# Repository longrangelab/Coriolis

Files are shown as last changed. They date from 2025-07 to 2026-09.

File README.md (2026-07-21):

# Coriolis
Coriolis is an open-source,long-range, digital platform that is capable of hosting a variety of sensors built for long-range precision shooters. 

Discord link for build questions or to chat about ideas: https://discord.gg/T3Q2JN2y2S

This video briefly describes Coriolis and what it can do: https://www.youtube.com/watch?v=9miKXuf_NCE&t=154s

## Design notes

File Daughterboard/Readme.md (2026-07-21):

# Coriolis Daughterboard

This directory contains the source files and manufacturing data for the Coriolis daughterboard. Unless you are experienced with electronics, I would recommend you select "PCB + Assembly." 

## Order a PCB

You can order this PCB directly from PCBWay using the link below.

<a href="https://www.pcbway.com/project/shareproject/Coriolis_Long_Range_Wind_Measurement_e642d0fc.html">
  Order Coriolis Daughterboard from PCBWay
</a>

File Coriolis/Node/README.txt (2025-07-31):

#####	HOW TO USE   #####
*For Target-Device
1.Uncomment line 11  #define IS_TARGET if this line is being commented
2.Upload to device ,check serial log

*For User-Device
1.Comment line 11  #define IS_TARGET if this line is being uncommented
2.Upload to device ,check serial log

If there is anything unusual, please let me know and I will correct it for you immediately.

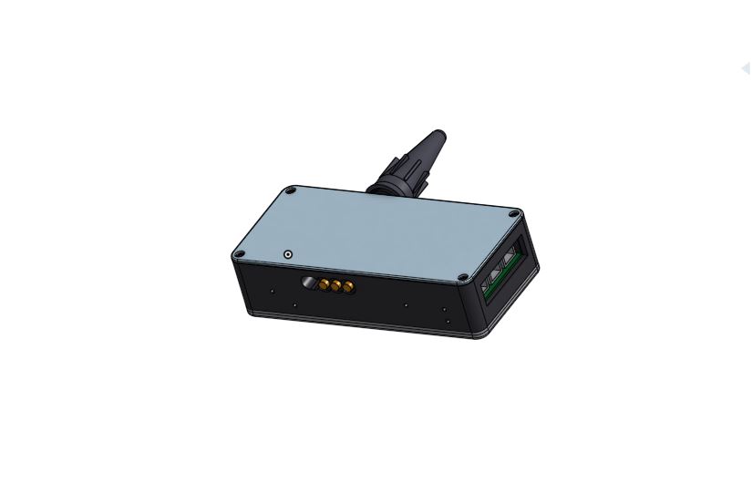
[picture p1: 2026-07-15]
Schematics and Photos/Color Case.JPG

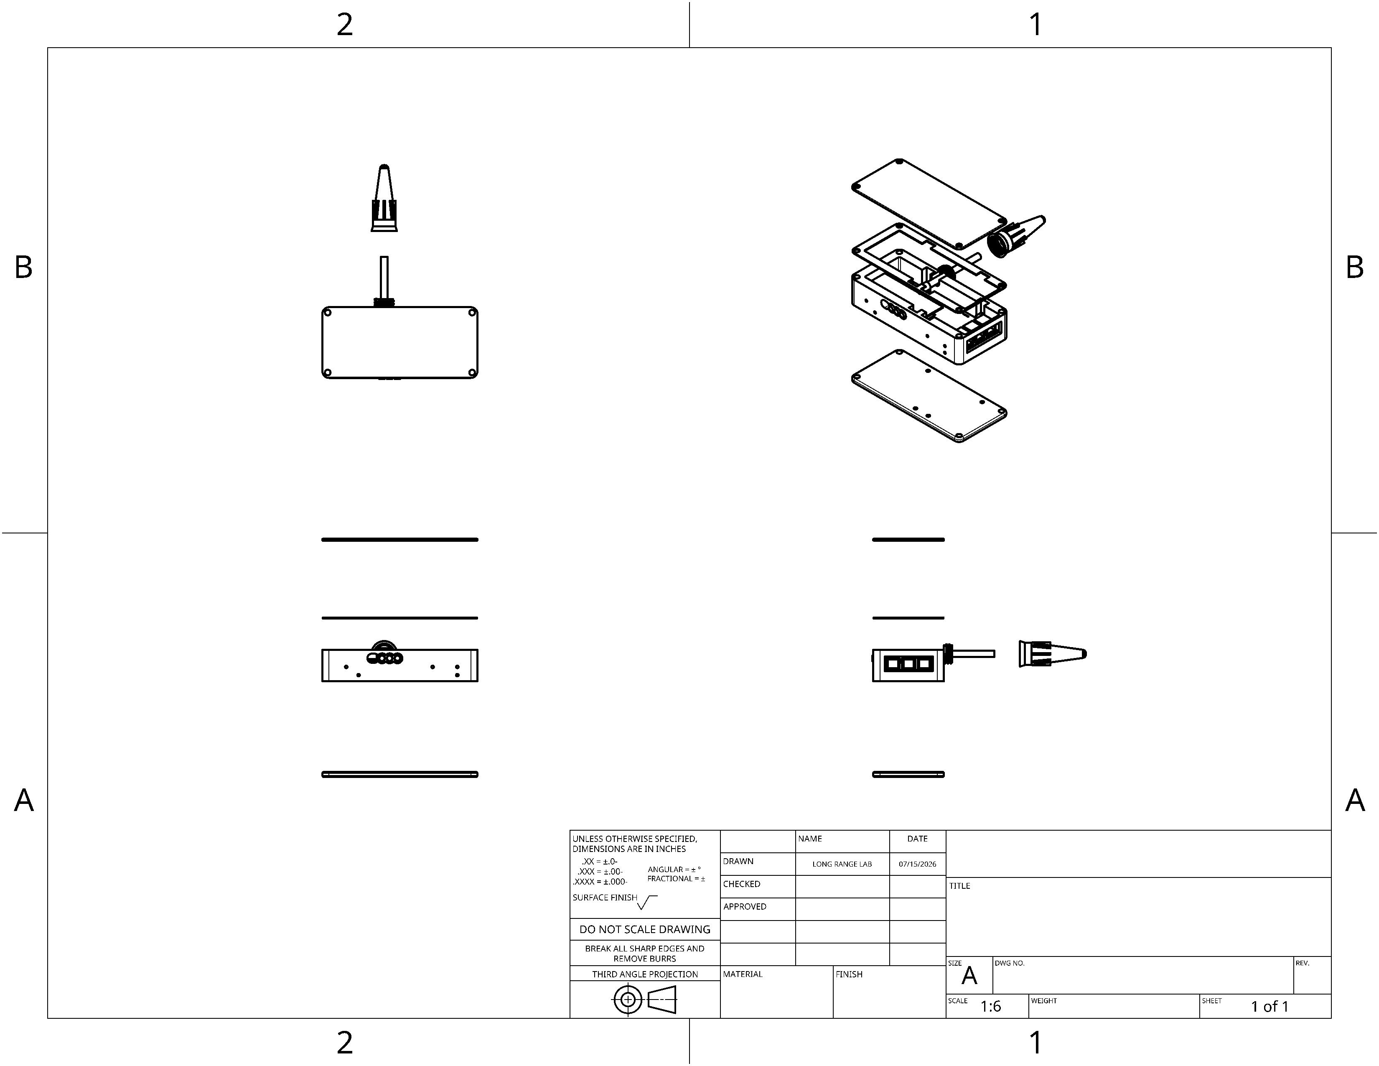
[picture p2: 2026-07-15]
Schematics and Photos/Github CaseDrawing.jpeg

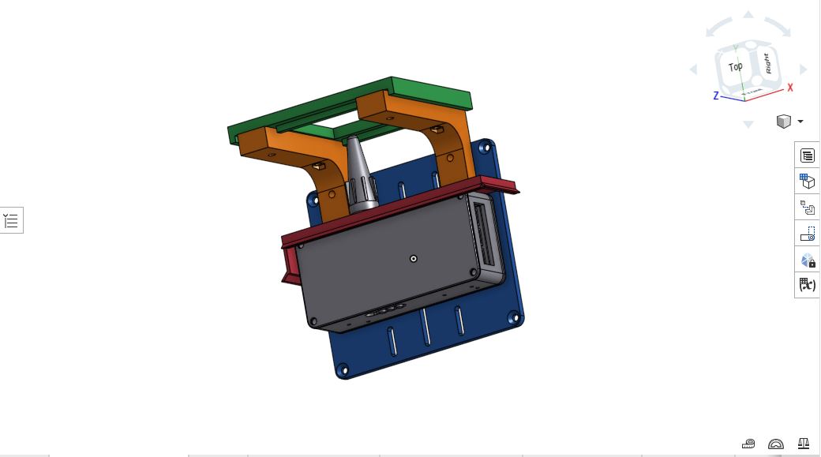
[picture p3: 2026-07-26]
Solar Panel Fixture/Solar node finished.JPG

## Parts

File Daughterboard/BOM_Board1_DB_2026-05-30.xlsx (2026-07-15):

No. | Quantity | Comment | Designator | Footprint | Value | Manufacturer Part | Manufacturer | Supplier Part | Supplier | Pins | Antenna Type | JLCPCB Stock | JLCPCB Price | Description | Diode Configuration
1 | 1 | 100nF | C1 | CAP-TH_L5.8-W2.4-P2.54-D0.6 | 100nF | CC1H104ZA1ED3F5P1100 | Dersonic(德尔创) | C2832506 | LCSC | 2 |  | 98323 | 0.0033 | Capacitance:100nF Tolerance:-20%~+80% Tolerance:-20%~+80% Voltage Rating:50V Pin Spacing:2.54mm Temperature Coefficient:Y5V Diameter:5.8mm Body Thickness:2.4mm
2 | 3 | R-RJ45R10P-B000 | J1,J2,J3 | RJ45-TH_R-RJ45R10P-B000 |  | R-RJ45R10P-B000 | Ckmtw(灿科盟) | C386758 | LCSC | 10 |  | 44898 | 0.0574 | Connector Type:RJ45 Jack Mounting Type:Right Angle Number of Ports:1 LED:Non-LED Shielding:Shielded Ratings:- Supplementary Features:Harpoon Contact (Plastic) Contact Material:Phosphor Bronze Contact Plating:Gold Operating Temperature:0℃~+70℃ Operating Te
3 | 3 | PM254V-11-04-H85 | J4_OLED,J4_SENSOR,J4_SENSOR1 | HDR-TH_4P-P2.54-V-F |  | PM254V-11-04-H85 | XFCN(兴飞) | C541851 | LCSC | 4 |  | 60552 | 0.0103 | Holes Structure:1x4P Pitch:2.54mm Row Spacing:- Circular Hole / Square Hole:Square Hole Mounting Type:Through Hole Number of Rows:1 Number of Positions:4P Current Rating:3A Holes Direction:Top Insulation Height:8.5mm Contact Material:Brass Contact Plating
4 | 1 | DY-333YD-SN-A3(EL) | LED1 | LED-TH_BD5.0-P2.54-FD-1 |  | DY-333YD-SN-A3(EL) | TONYU(东裕) | C7470706 | LCSC | 2 |  | 852 | 0.0056 | Lamp Holder Type:5mm round lamp head Illumination Color:Yellow Voltage - Forward(Vf):2.4V Voltage - Forward(Vf):2.4V Power(Watts):60mW Forward Current:20mA Wavelength - Dominant:592nm Wavelength - Dominant:592nm Peak Wavelength:584nm Diode Configuration:D | Discrete Diode
5 | 1 | 100Ω | R1 | RES-TH_BD2.4-L6.3-P10.30-D0.6 | 100Ω | MFR50SJT-52-100R | YAGEO(国巨) | C176622 | LCSC | 2 |  | 4514 | 0.0023 | Type:Metal Film Resistors Resistance: Tolerance:±5% Tolerance:±5% Power(Watts):500mW Operating Temperature:-55℃~+155℃ Operating Temperature:-55℃~+155℃
6 | 2 | 10kΩ | R2,R3 | RES-TH_BD2.4-L6.3-P10.30-D0.6 | 10kΩ | MFR50SJT-52-10K | YAGEO(国巨) | C176623 | LCSC | 2 |  | 2140 | 0.0025 | Type:Metal Film Resistor Resistance:10kΩ Tolerance:±5% Tolerance:±5% Voltage-Supply(Max):- Power(Watts):500mW Operating Temperature:-55℃~+155℃ Operating Temperature:-55℃~+155℃
7 | 2 | 4.7kΩ | R4,R5 | RES-TH_BD2.2-L6.5-P10.50-D0.6 | 4.7kΩ | MFR50SJT-52-4K7 | YAGEO(国巨) | C176641 | LCSC | 2 |  | 9861 | 0.0024 | Type:Metal Film Resistors Resistance: Tolerance:±5% Tolerance:±5% Power(Watts):500mW Operating Temperature:-55℃~+155℃ Operating Temperature:-55℃~+155℃
8 | 2 | FH-00780 | U4,U5 | HDR-TH_13P-P2.54-V-F |  | FH-00780 | Liansheng(连盛) | C2685211 | LCSC | 13 |  | 3597 | 0.0174 | Holes Structure:1x13P Pitch:2.54mm Row Spacing:- Circular Hole / Square Hole:Square Holes Mounting Type:Straight Number of Rows:Plugin Number of Holes:13P Current Rating (Max):3A Voltage Rating (Max):- Holes Direction:Top Insulation Height:8.5mm Operating
9 | 1 | DS1009-08AT1NX-0A2 | U6 | DIP-8_L10.2-W10.2-P2.54-LS7.6-BL |  | DS1009-08AT1NX-0A2 | CONNFLY | C72124 | LCSC | 8 |  | 68990 | 0.0043 | Adaptation Package Type:DIP Pitch:2.54mm Row Spacing:7.62mm Circular Holes/Square Holes:Square Hole Number of Positions:8P Contact Plating:Tin Operating Temperature:-20℃~+105℃ Operating Temperature:-20℃~+105℃

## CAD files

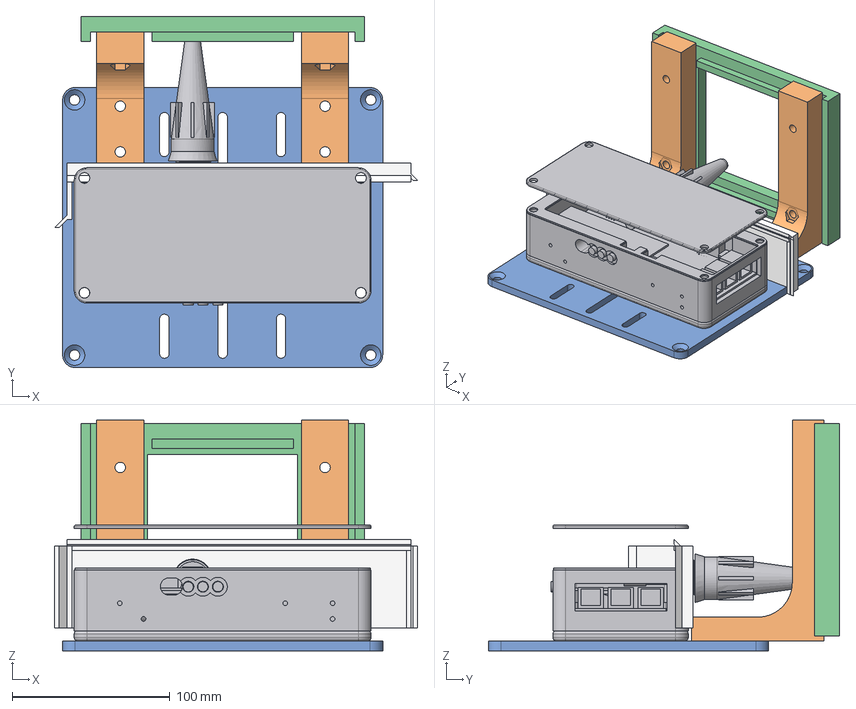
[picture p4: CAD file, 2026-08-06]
Solar Panel Fixture/Solar Node Complete.step
230.4 x 222.9 x 146.3 mm
riser_L
platform
backer_plate
riser_R
node x 21

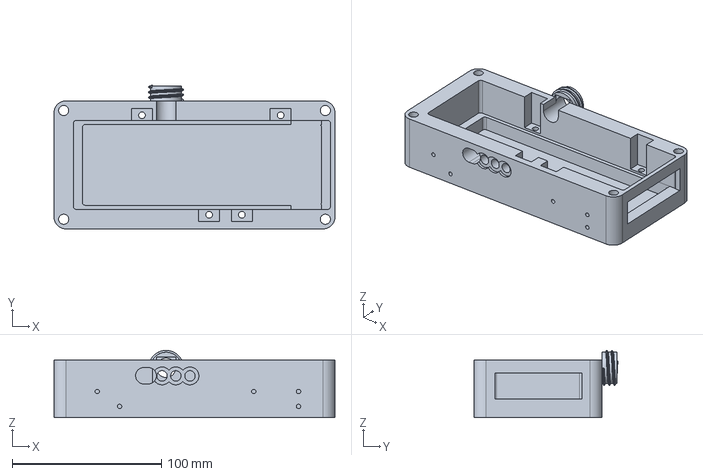
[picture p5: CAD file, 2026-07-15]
STL's/Individual Case Parts/Main Enclosure.step
188.5 x 96.5 x 45.1 mm

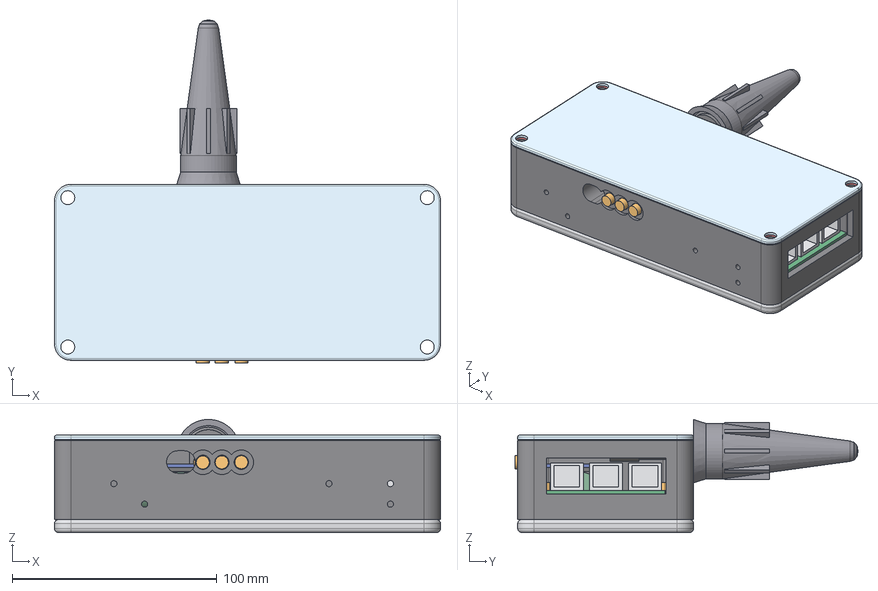
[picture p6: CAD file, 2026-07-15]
STL's/Daughterboard Case V1.step
188.5 x 167.6 x 55.2 mm
TBeam_antenna_whip
carrier_pcb
base_aluminum
strap_1
push_button_x3_v7 x 3
strap_4
lid_clear
TBeam_antenna_base
middle_printed
antenna_cover
RJ45_J1
strap_3
gasket_tpu_v8
TBeam_18650_holder
RJ45_J2
strap_2
RJ45_J3
TBeam_PCB
TBeam_18650_cell

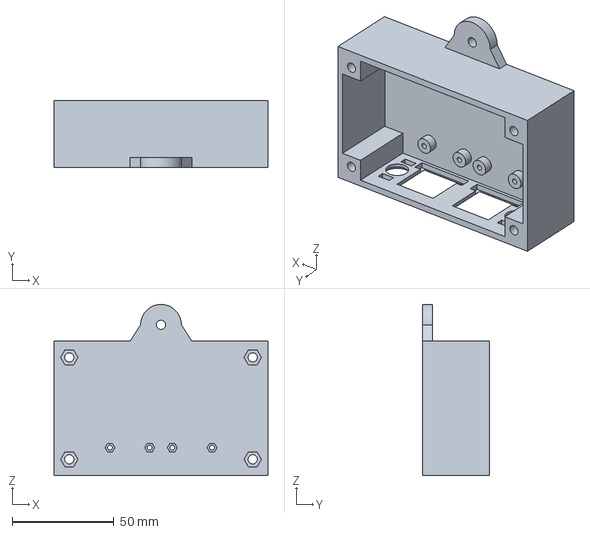
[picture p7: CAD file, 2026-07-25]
STL's/Wind Meter Mounting Options/rj45_body.step
105.0 x 33.0 x 84.0 mm

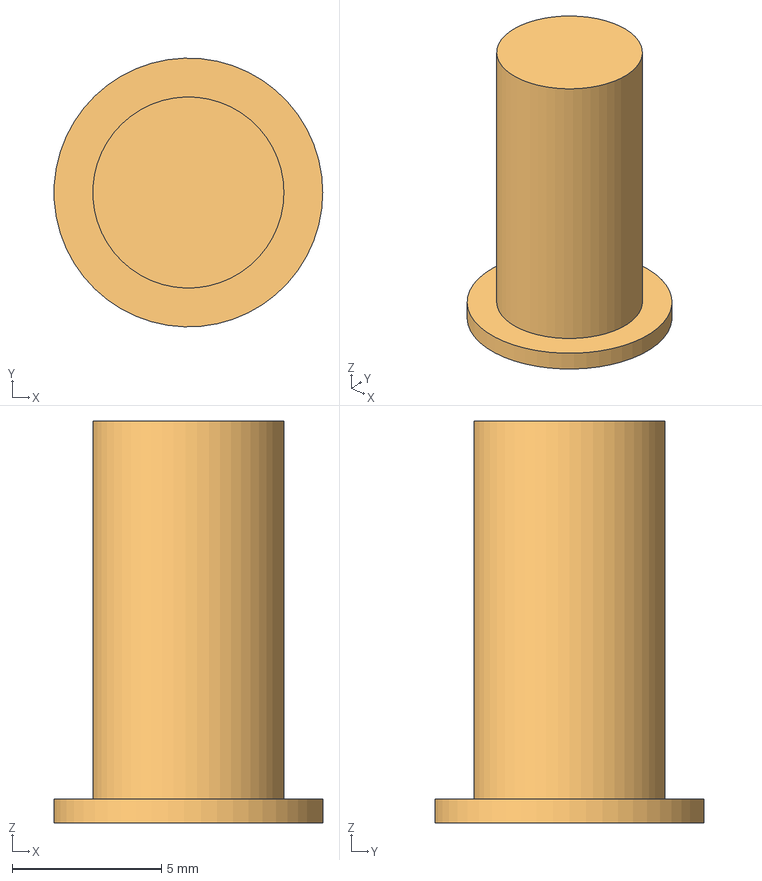
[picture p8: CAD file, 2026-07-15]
STL's/Individual Case Parts/Push Button.step
8.99 x 9.00 x 13.5 mm

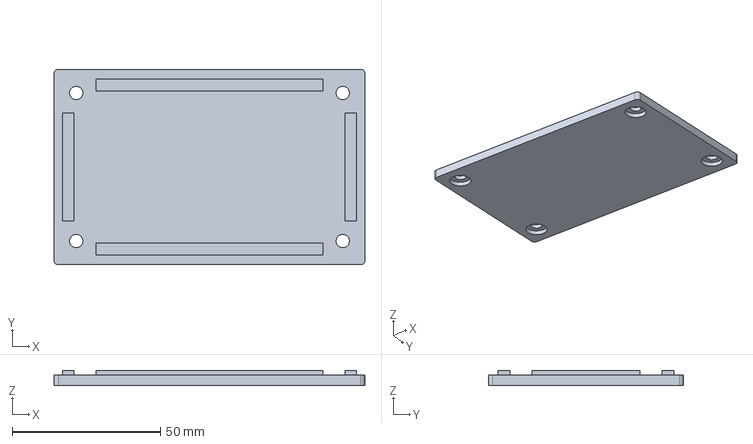
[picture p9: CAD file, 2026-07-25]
STL's/Wind Meter Mounting Options/rj45_lid.step
105.0 x 66.0 x 5.10 mm

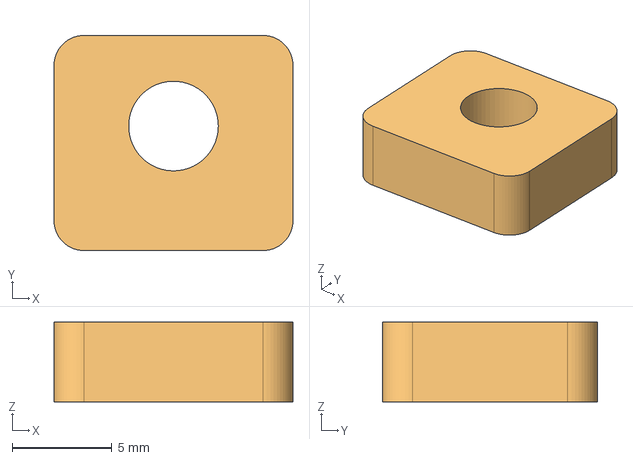
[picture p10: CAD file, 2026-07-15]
STL's/Individual Case Parts/PCB Strap.step
12.0 x 10.8 x 4.00 mm

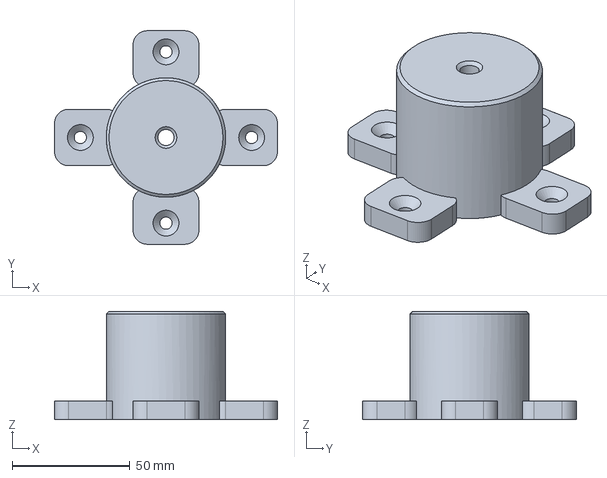
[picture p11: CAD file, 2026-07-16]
STL's/Wind Meter Mounting Options/Ballhead Post Mount.step
94.8 x 90.8 x 46.1 mm

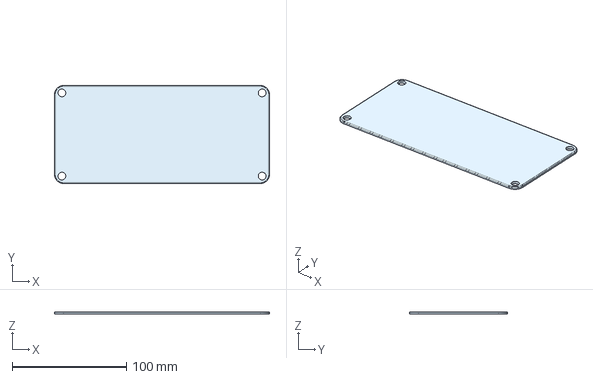
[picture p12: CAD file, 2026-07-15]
STL's/Individual Case Parts/2mm Acrylic Lid.step
188.5 x 85.9 x 2.16 mm

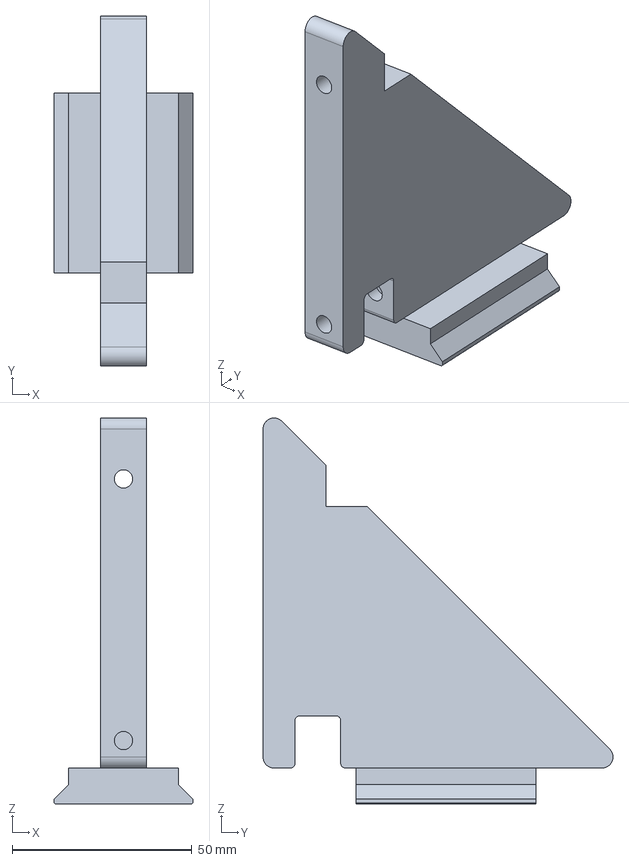
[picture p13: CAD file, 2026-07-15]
STL's/Wind Meter Mounting Options/Inspeed Arca Mount.step
38.6 x 97.3 x 107.3 mm

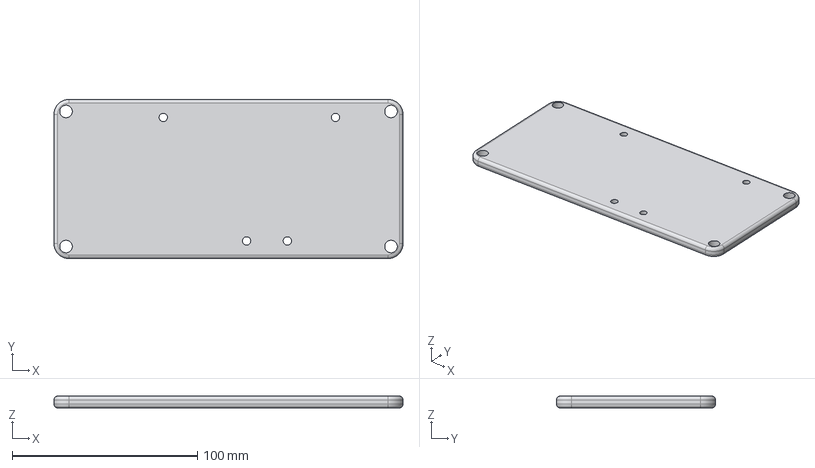
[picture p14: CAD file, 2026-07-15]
STL's/Individual Case Parts/Optional - Aluminum Bottom.step
188.5 x 85.9 x 6.35 mm

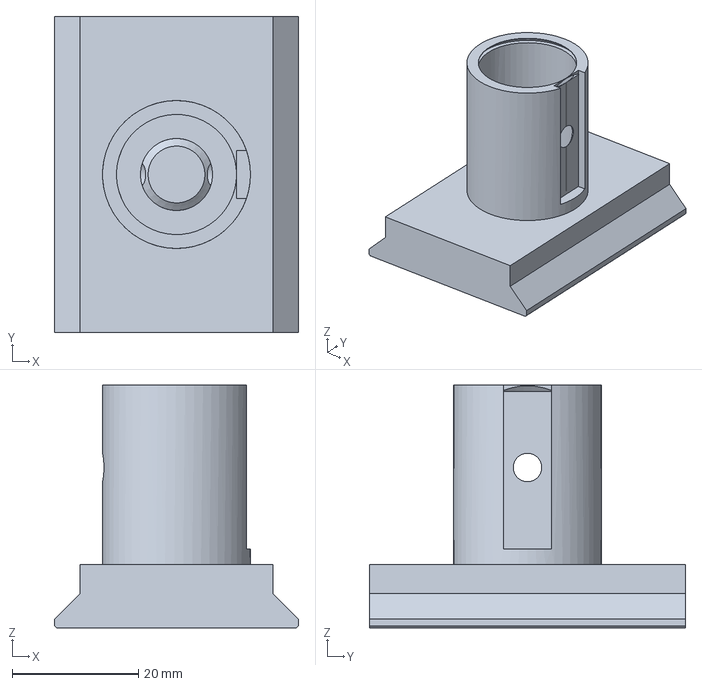
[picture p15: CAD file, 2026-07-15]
STL's/Wind Meter Mounting Options/Sparkfun Wind Arm Arca Mount.step
38.6 x 50.0 x 38.4 mm

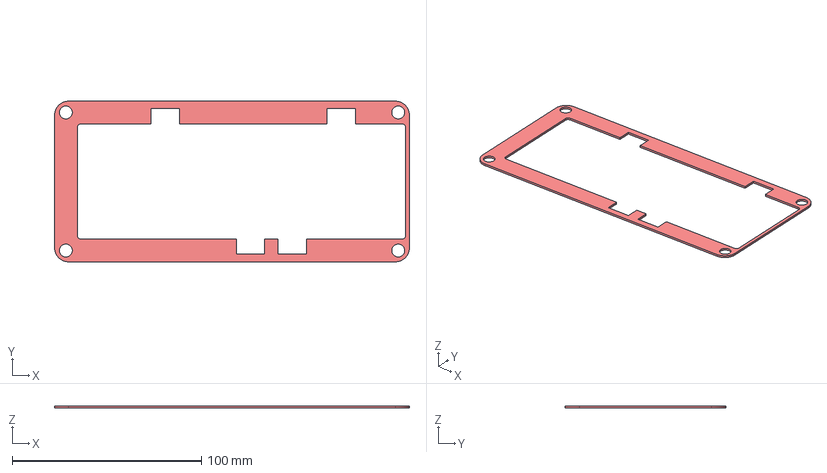
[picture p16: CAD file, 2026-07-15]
STL's/Individual Case Parts/TPU Lid Gasket.step
187.5 x 84.9 x 1.20 mm

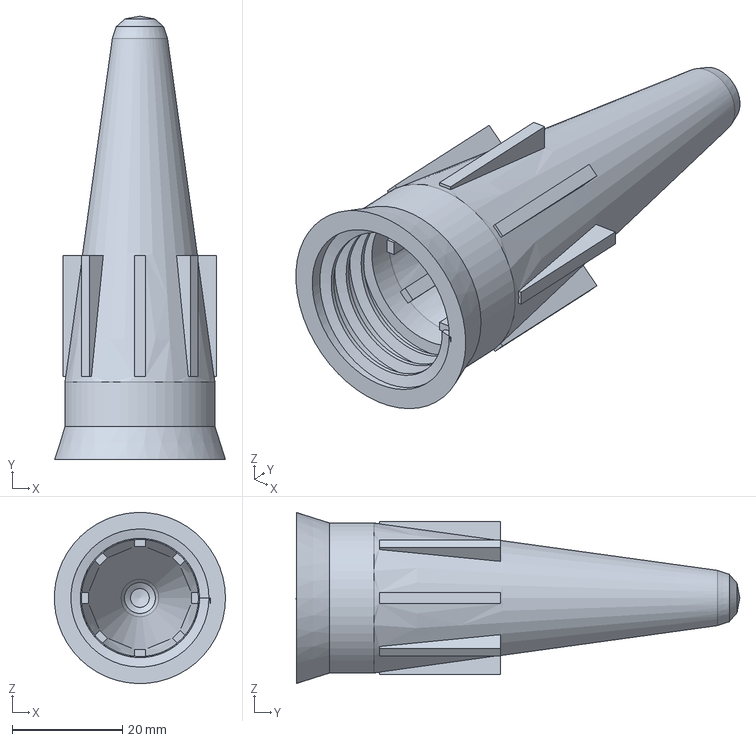
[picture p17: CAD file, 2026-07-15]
STL's/Individual Case Parts/Screw-On Cover for Factory Antenna.step
31.0 x 80.3 x 31.0 mm

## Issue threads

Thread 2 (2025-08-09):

3D models?

edgan, 2025-08-09:
There are currently no 3D models(STLs?) in the git repository.

edgan, 2025-08-13:
I see that. The directory structure should be improved.

`Weather Meter V1.0` -> `3d-models/weather-meter`

Using anything like `v1.0` in a directory name in git is silliness. That is what tags and releases are for.

Also the filenames are so long I can't even see they are `STL` files.

I will make a pull request for the naming.

There is no STLs for the dial part. I will make a new issue for that.

Closed 2025-08-13.

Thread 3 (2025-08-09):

Detailed parts list?

edgan, 2025-08-09:
Pulled from the YouTube video:
Mounting – 3D-printed PLA bracket ([Arken Optics LH4 6-24](https://opticsforce.com/products/arken-optics-lh4-6-24x50-ffp-capped-tool-less-turrets-illuminated-vhr-vpr-30mm-tube), discontinued).

Motion – Stepper motor + 5:1 gearbox for torque, driven by a [DRV8825](https://www.pololu.com/product/2133) driver.

Power – RC car battery.

Control – [Arduino](https://www.arduino.cc/) microcontroller running simple but precise early-stage firmware.

Ideas:
1. 3D models https://github.com/longrangelab/Coriolis/issues/2
2. Motors
3. Batteries, voltage? 2S, 4S, or 6S?
4. Scope, given the current one is discontinued, support different obtainable scopes
5. Exact Arduino boards
6. Multiple links for products and places to purchase. Manufacture, Amazon, etc

longrangelab, 2025-08-16:
Still working on this at the moment. I have listed the main parts for the Weather Station, the Base Unit, and the Target unit. Still selecting final components for FAWD and the User Interface.

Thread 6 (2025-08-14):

Help with PCBs

MitkoDyakov, 2025-08-14:
Cool project. I can help you with PCB design if you are okay with KiCAd?

longrangelab, 2025-08-16:
We currently have a prototype PCB that we are looking to get made soon. I will let you know if we need any help! Thank you so much for following this project!

Closed 2025-08-16.

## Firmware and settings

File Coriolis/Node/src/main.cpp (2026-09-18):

/**
 * Wind Node  -  LiLyGO T-Beam (ESP32, v1.1 or v1.2)
 * =================================================
 * TDMA node: listens for the base-station BEACON, transmits its NodePacket in
 * its slot, and falls back to autonomous jittered transmit if no beacon.
 *
 * Battery savers:
 *   - OLED sleeps after 20 s; wake with the center button (GPIO 38)
 *   - GPS powers DOWN after the first fix (stationary meter needs position once)
 *   - CPU dropped to 80 MHz, WiFi/BT off
 *   - Sensors read once per transmit cycle (not on a fast timer)
 *
 * Creature comfort:
 *   - Change the node number in the field: long-press to enter SET NODE ID,
 *     short-press to increment, long-press to save (persists in flash/NVS).
 *     No reflashing to renumber a meter.
 */

#include <Arduino.h>
#include <Wire.h>
#include <Preferences.h>
#include <WiFi.h>
#include <esp_sleep.h>
#include <esp_system.h>          // esp_restart() -- I2C recovery last resort

#include "screen.h"
#include "Power.h"
#include "Environment.h"          // BMP085Sensor (baro) + GPSModule (GPS)
#include "telemetry.h"

//#define USE_TSL2591            // uncomment when the TSL2591 is installed
#ifdef USE_TSL2591
  #include "Light.h"
#endif

// ============================================================================
// CONFIGURATION
// ============================================================================
#define DEFAULT_NODE_ID     1        // used only until you set/save one via button
#define MAX_NODE_ID         15

#define I2C_SDA             21
#define I2C_SCL             22
#define GPS_RX_PIN          34
#define GPS_TX_PIN          12
#define ATTINY_ADDR         0x42
#define ATTINY_BYTES        12
#define BUTTON_PIN          38       // center/user button (active low)

#define DISPLAY_TIMEOUT_MS  20000UL  // OLED sleeps after this idle time
#define LONG_PRESS_MS       1200UL
#define EDIT_TIMEOUT_MS     8000UL

#define GPS_SLEEP_AFTER_FIX 1        // 1 = power GPS down once we have a position
#define AUTO_TX_MS          3000UL   // fallback transmit period (no beacon)
#define AUTO_JITTER_MS      500

// ============================================================================
// DEEP SLEEP (piece 2 of 3 -- see DEEPSLEEP_v6.md)
// ============================================================================
// The base commands sleep by setting BFLAG_SLEEP_CMD in its beacons. We ack
// (FLAG_SLEEP_ACK on our next TX) and drop into ESP32 deep sleep. On each
// timer wake we listen for a beacon: still commanding sleep -> transmit one
// reading and sleep again; not commanding sleep (or BFLAG_WAKE_CMD) -> stay up.
//
// The DUTY CYCLE -- how long we sleep between check-ins -- is chosen LOCALLY
// from battery voltage and temperature (see chooseDutySec). Local is the right
// place for this decision: the node knows its own battery, and different nodes
// can be in different shape (one shaded, one in sun).
#define SLEEP_DUTY_MIN_S     20      // default duty: warm + charged
#define SLEEP_DUTY_MAX_S     300     // deep-winter floor: check in every 5 min
#define SLEEP_LISTEN_MIN_MS  2500UL  // beacon-listen window bounds on wake
#define SLEEP_LISTEN_MAX_MS  16000UL

// ---- I2C bus recovery -------------------------------------------------------
// The ATtiny wind sensor shares the I2C bus with the PMU and OLED. The classic
// failure is a peripheral left holding SDA low mid-byte, which hangs the bus
// and NACKs every subsequent transfer. Recovery escalates:
//   1) after I2C_NACK_LIMIT consecutive failed reads -> clock the bus free
//      (bit-bang up to 9 SCL pulses so a stuck slave finishes its byte) and
//      re-init Wire. This fixes the common hang WITHOUT losing state.
//   2) if that still doesn't help after I2C_RECOVER_LIMIT attempts in a row ->
//      full esp_restart() as a last resort. A reboot counter prevents a boot
//      loop: a node that can't recover falls back to headless/stale operation
//      and keeps transmitting what it can rather than restarting forever.
#define I2C_NACK_LIMIT       5    // consecutive read fails -> attempt bus clear
#define I2C_RECOVER_LIMIT    4    // bus clears that didn't help -> allow a reset
#define I2C_MAX_RESETS       3    // hard cap on self-resets before giving up

// ---- cold-charge cutoff (protect the Li-ion cell) --------------------------
// Charging a lithium cell below freezing plates lithium: permanent capacity
// loss and, worst case, an internal short. The PMU can gate charging but the
// stock T-Beam has no thermistor on the cell, so we enforce it in firmware from
// the BMP180 ambient reading (a proxy: bias the cutoff a few degrees above 0 C
// since the cell may be colder than the air and the sensor lags). Two thresholds
// give hysteresis so charging doesn't chatter near the boundary. The decision is
// re-evaluated on every sensor read, i.e. every awake cycle and every wake from
// deep sleep -- and the PMU keeps the setting while the ESP32 sleeps.
#define COLD_CHARGE_CUTOFF_C   3.0f  // at/below this ambient, DISABLE charging
#define COLD_CHARGE_RESUME_C   6.0f  // only re-ENABLE once we warm past this
// What to do when the temperature is UNREADABLE (BMP180 glitch, or absent) AND
// the node is asleep. 0 = fail safe: no trusted temp -> no charging (default).
// Awake nodes are exempt from the gate entirely and charge regardless, so this
// only affects a DEPLOYED (sleeping) node -- one with no working BMP180 won't
// charge while deployed. Set to 1 if you ever field a baro-less solar node.
#define COLD_CHARGE_FAILSAFE_ALLOW  0
#define SLEEP_SILENT_LIMIT   3       // this many wakes w/o beacon -> assume base
                                     // off, escalate duty to save power
#define BUTTON_WAKE_GRACE_MS 60000UL // after a button wake, ignore sleep cmds
                                     // this long so a human can read the screen

// ============================================================================
// ATtiny wire struct (must match attiny85_wind_sensor.ino)
// ============================================================================
struct AttinyWind { uint16_t speed_avg, speed_sd, dir_avg, dir_sd, gust, rawADC; };

// ============================================================================
// GLOBALS
// ============================================================================
Screen*        screen = nullptr;
AXPManagement  power(I2C_SDA, I2C_SCL);
BMP085Sensor   baro;
GPSModule      gps(Serial1, GPS_RX_PIN, GPS_TX_PIN);
NodeRadio      radio;
Preferences    prefs;
#ifdef USE_TSL2591
  LightSensor  light;
#endif

uint8_t    nodeId = DEFAULT_NODE_ID;
bool       baroOk = false, attinyOk = false;

// ---- state that must SURVIVE deep sleep (RTC slow memory, ~8 KB) ----
// Ordinary globals are lost on deep sleep (it's a reboot). Everything the node
// needs to resume without re-doing work lives here: whether we're in sleep
// mode, the duty we chose, the last known TDMA cycle length (sizes the beacon
// listen window), a counter of beacon-less wakes, and -- the big one -- the GPS
// fix. Without the RTC-cached fix, every wake would re-power the GPS and burn
// 30+ s at ~40 mA hunting satellites, which would erase the entire point of
// sleeping.
RTC_DATA_ATTR bool     rtcSleepMode   = false;
RTC_DATA_ATTR uint16_t rtcDutySec     = SLEEP_DUTY_MIN_S;
RTC_DATA_ATTR uint16_t rtcCycleMs     = (MIN_SLOTS + 1) * SLOT_MS;
RTC_DATA_ATTR uint8_t  rtcSilentWakes = 0;
// I2C self-reset counter, persisted so a deployed (sleeping) node can't boot-loop
// on a permanently stuck bus: after I2C_MAX_RESETS it stops resetting and just
// runs degraded. Cleared once a read succeeds (see readAttiny recovery path).
RTC_DATA_ATTR uint8_t  rtcI2cResets   = 0;
// Failure-run counters, RTC-persisted so escalation accumulates even in sleep
// mode -- there the node reads once per wake then deep-sleeps (a reboot), so
// plain statics would reset every wake and never reach the recovery threshold.
RTC_DATA_ATTR uint8_t  rtcNackRun     = 0;   // consecutive failed reads
RTC_DATA_ATTR uint8_t  rtcClearRun    = 0;   // consecutive bus-clears that didn't help
RTC_DATA_ATTR bool     rtcGpsFix      = false;
RTC_DATA_ATTR double   rtcLat = 0, rtcLon = 0;
RTC_DATA_ATTR uint32_t rtcWakeCount   = 0;
// Cold-charge cutoff state, persisted across deep sleep so hysteresis carries
// over between wakes (and matches what the PMU is actually doing). Starts true:
// on a fresh boot charging is allowed until the first reading says otherwise.
RTC_DATA_ATTR bool     rtcChargeAllowed = true;

// GPS (cached once, then powered down)
bool       gpsFixCached = false;
double     cachedLat = 0, cachedLon = 0;

// sleep bookkeeping (normal RAM -- valid only while awake)
bool       quickWake = false;          // this boot is a timer wake from sleep
uint32_t   sleepIgnoreUntil = 0;       // button-wake grace window
bool       pendingSleepAck = false;    // next slot TX should carry the ack

// wind hold-last-good
AttinyWind lastWind = {0,0,0,0,0,0};
bool       haveWind = false;
uint32_t   lastWindMs = 0;              // when the last successful ATtiny read landed

// How long a held-over wind reading stays trustworthy. The ATtiny publishes a
// fresh 2 s window continuously, so anything older than this means the I2C link
// or the meter itself is down -- past that we mark the wind INVALID rather than
// keep transmitting a stale value that looks live.
#define WIND_STALE_MS  30000UL

// most recent reading (for the display)
NodeReading current;

// TDMA state
bool       synced = false;
uint32_t   beaconLocalMs = 0, lastBeaconAnyMs = 0, lastAutoTx = 0;
uint16_t   slotMs = SLOT_MS, cycleMs = (MIN_SLOTS + 1) * SLOT_MS;
uint8_t    maxSlot = MIN_SLOTS;
uint16_t   nodeMask = 0;      // v4: slot map from the last beacon (bit i => id i scheduled)
uint8_t    mySlot = 0;        // v4: our compact slot this cycle (0 = not scheduled yet)
bool       txThisCycle = false;

// UI / display
bool       displayOn = true, editMode = false;
uint32_t   lastActivity = 0, editLastMs = 0, lastDraw = 0;

// button
int        btnPrev = HIGH;
uint32_t   pressStart = 0;
bool       longFired = false;

// ============================================================================
// HELPERS
// ============================================================================
const char* dirName(int deg) {
    static const char* n[] = {"N","NE","E","SE","S","SW","W","NW"};
    int i = ((deg + 22) / 45) % 8; if (i < 0) i += 8; return n[i];
}

// Raw single-shot read of the ATtiny wind sensor. Returns false on any I2C
// short-read (NACK / stuck bus). No recovery here -- that's readAttiny()'s job.
static bool readAttinyRaw(AttinyWind& w) {
    if (Wire.requestFrom(ATTINY_ADDR, (uint8_t)ATTINY_BYTES) != ATTINY_BYTES) return false;
    uint8_t b[ATTINY_BYTES];
    for (uint8_t i = 0; i < ATTINY_BYTES; i++) b[i] = Wire.read();
    w.speed_avg = b[0]|(b[1]<<8); w.speed_sd = b[2]|(b[3]<<8);
    w.dir_avg   = b[4]|(b[5]<<8); w.dir_sd   = b[6]|(b[7]<<8);
    w.gust      = b[8]|(b[9]<<8); w.rawADC   = b[10]|(b[11]<<8);
    return true;
}

// Clock a stuck I2C bus free. A slave that was interrupted mid-byte can hold
// SDA low forever; pulsing SCL lets it finish its transaction and release the
// line. We end the Wire driver, bit-bang up to 9 SCL pulses (a full byte + ack)
// while SDA is released, issue a manual STOP, then re-init Wire. No reboot, no
// lost state -- this alone clears the common hang.
static void i2cBusClear() {
    Wire.end();
    pinMode(I2C_SCL, OUTPUT_OPEN_DRAIN);
    pinMode(I2C_SDA, INPUT_PULLUP);              // release SDA, watch it
    for (uint8_t i = 0; i < 9 && digitalRead(I2C_SDA) == LOW; i++) {
        digitalWrite(I2C_SCL, LOW);  delayMicroseconds(5);
        digitalWrite(I2C_SCL, HIGH); delayMicroseconds(5);
    }
    // manual STOP: SDA low->high while SCL high
    pinMode(I2C_SDA, OUTPUT_OPEN_DRAIN);
    digitalWrite(I2C_SDA, LOW);  delayMicroseconds(5);
    digitalWrite(I2C_SCL, HIGH); delayMicroseconds(5);
    digitalWrite(I2C_SDA, HIGH); delayMicroseconds(5);
    Wire.begin(I2C_SDA, I2C_SCL);
}

// ATtiny read with tiered bus recovery. Most calls just succeed and reset the
// failure counters. On a run of failures it clears the bus; if clearing the bus
// repeatedly fails to help, it allows a bounded self-reset (RTC-counted so a
// permanently stuck node degrades gracefully instead of boot-looping).
bool readAttiny(AttinyWind& w) {
    if (readAttinyRaw(w)) {          // success -> everything resets
        rtcNackRun = 0; rtcClearRun = 0; rtcI2cResets = 0;
        return true;
    }

    if (++rtcNackRun < I2C_NACK_LIMIT) return false;  // tolerate a few, stay degraded

    // Threshold hit -> try to clock the bus free and read once more.
    Serial.printf("[i2c] %u consecutive NACKs -> bus clear\n", rtcNackRun);
    i2cBusClear();
    rtcNackRun = 0;
    if (readAttinyRaw(w)) { rtcClearRun = 0; rtcI2cResets = 0; return true; }

    // Bus clear didn't restore comms.
    if (++rtcClearRun < I2C_RECOVER_LIMIT) return false;
    rtcClearRun = 0;

    // Last resort: bounded self-reset. Skip once the cap is hit so a hard-stuck
    // node keeps running headless/stale rather than restarting forever.
    if (rtcI2cResets < I2C_MAX_RESETS) {
        rtcI2cResets++;
        Serial.printf("[i2c] bus unrecoverable -> self-reset %u/%u\n",
                      rtcI2cResets, I2C_MAX_RESETS);
        Serial.flush();
        esp_restart();               // no return
    }
    Serial.println(F("[i2c] reset cap reached -> running degraded (wind invalid)"));
    return false;
}

// Cold-charge decision with hysteresis. `prevAllowed` is the current state, so
// the band between CUTOFF and RESUME holds whatever we were doing (no chatter).
// Unreadable temperature falls back to COLD_CHARGE_FAILSAFE_ALLOW.
bool decideCharge(float tempC, bool tempValid, bool prevAllowed) {
    if (!tempValid) return (bool)COLD_CHARGE_FAILSAFE_ALLOW;   // no trusted temp
    if (prevAllowed) return tempC >  COLD_CHARGE_CUTOFF_C;     // charging -> cut when cold
    else             return tempC >= COLD_CHARGE_RESUME_C;     // held off -> resume when warm
}

// Apply the cutoff to the PMU, but only when the state actually changes and the
// PMU accepted the call -- so we don't spam I2C, and we retry if the PMU wasn't
// ready. Called at the end of readSensors, i.e. on every awake cycle and on
// every wake from deep sleep, which is exactly the "re-probe on wake" behaviour.
void applyColdChargePolicy(const NodeReading& r) {
    // Cold-charge protection applies ONLY to deployed nodes -- ones in, or
    // entering, sleep mode (the permanently-stationed solar units that sit
    // unattended through winter). An AWAKE node is attended and runs its radio
    // continuously, so it rarely net-charges in the cold and is allowed to charge
    // WITHOUT the temperature gate -- and doesn't need a working BMP180 to charge.
    // (Note: awake does not strictly mean above freezing -- you can shoot below 0
    // -- but an awake node's high, steady draw makes cold-charging a non-issue.)
    bool sleeping = rtcSleepMode || pendingSleepAck;   // pendingSleepAck => this is
                                                       // the transition-to-sleep cycle
    bool allow = sleeping ? decideCharge(r.temperatureC, r.baroValid, rtcChargeAllowed)
                          : true;                      // awake -> unconditional charge
    if (allow == rtcChargeAllowed) return;
    if (power.setChargeEnable(allow)) {
        rtcChargeAllowed = allow;
        if (allow)
            Serial.println(F("[charge] ENABLED"));
        else if (r.baroValid)
            Serial.printf("[charge] DISABLED -- cold-guard (ambient %.1f C <= %.1f)\n",
                          r.temperatureC, (float)COLD_CHARGE_CUTOFF_C);
        else
            Serial.println(F("[charge] DISABLED -- temp unreadable while asleep (fail-safe)"));
    }
}

// Read every sensor into r (called once per transmit cycle).
void readSensors(NodeReading& r) {
    AttinyWind w;
    attinyOk = readAttiny(w);
    if (attinyOk) { lastWind = w; haveWind = true; lastWindMs = millis(); }
    if (haveWind) {
        r.windSpeed   = lastWind.speed_avg / 100.0f;
        r.windSpeedSd = lastWind.speed_sd  / 100.0f;
        r.windDir     = lastWind.dir_avg   / 10.0f;
        r.windDirSd   = lastWind.dir_sd    / 10.0f;
        r.windGust    = lastWind.gust      / 100.0f;
    }
    // Tell the receiver whether to trust these numbers at all. If we've never
    // read the meter, or the last good read has gone stale, the fields above
    // are 0 or old -- flagging that is what stops a dead anemometer from
    // quietly pulling the network's weighted average toward "calm".
    r.windValid = haveWind && ((uint32_t)(millis() - lastWindMs) < WIND_STALE_MS);
    if (!r.windValid && haveWind)
        Serial.println(F("[ATtiny] wind STALE -- transmitting as invalid"));
    if (baroOk) {
        r.temperatureC = baro.readTemperatureC();
        r.pressurePa   = baro.readPressurePa();
        r.baroValid    = (r.pressurePa > 30000.0f && r.pressurePa < 120000.0f);
    }
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
void loop() {
    // ---- 1) beacon sync ----
    BeaconPacket b;
    if (radio.pollBeacon(b)) {
        beaconLocalMs = millis(); lastBeaconAnyMs = millis();
        slotMs = b.slot_ms; cycleMs = b.cycle_ms; maxSlot = b.max_slot;
        nodeMask = b.node_mask;                    // v4 compact slot map
        mySlot   = beaconSlotOf(nodeMask, nodeId); // our rank-based slot (0 = not scheduled)
        synced = true; txThisCycle = false;
        rtcCycleMs = b.cycle_ms;               // keep the wake listen window sized

        // Sleep command from the base. We don't sleep HERE -- we set a flag so
        // the very next slot transmission carries FLAG_SLEEP_ACK, and sleep
        // right after that TX completes. Ack-then-sleep, always in that order:
        // the base needs to hear the confirmation to show "N nodes acked".
        //
        // v5: we sleep if EITHER the fleet-wide flag is set OR our own bit is set
        // in the beacon's per-node sleep_mask. The two are independent overrides;
        // a per-node command sleeps us even while the rest of the fleet is awake.
        bool sleepMe = (b.flags & BFLAG_SLEEP_CMD) || ((b.sleep_mask >> nodeId) & 1u);
        if (sleepMe && millis() >= sleepIgnoreUntil) {
            pendingSleepAck = true;
        } else if (!sleepMe) {
            pendingSleepAck = false;           // base changed its mind pre-TX
            rtcSleepMode = false;
        }
    }

    // ---- 2) transmit scheduling ----
    if (synced) {
        // v4: our slot is our RANK in the beacon's node_mask, not our raw id.
        // mySlot == 0 means the base hasn't scheduled us yet (it hasn't heard us
        // since we (re)joined) -- fall through to the jitter path so it adds us.
        uint32_t myOffset = (uint32_t)mySlot * slotMs;
        bool fits = (mySlot >= 1) && (myOffset + slotMs <= cycleMs);
        if (fits) {
            if (!txThisCycle && (millis() - beaconLocalMs) >= myOffset) {
                NodeReading r; readSensors(r);
                radio.sendData(r, nodeId, pendingSleepAck);
                txThisCycle = true;
                printReading(r);
                if (pendingSleepAck) {          // ack sent -> commit to sleep
                    rtcSleepMode = true;
                    rtcSilentWakes = 0;
                    rtcGpsFix = gpsFixCached; rtcLat = cachedLat; rtcLon = cachedLon;
                    enterDeepSleep(nextDuty(r));  // no return
                }
            }
        } else {
            // not yet in the schedule -> jitter in so the base hears us and adds
            // our bit to node_mask; next beacon we get a real slot.
            if (millis() - lastAutoTx > (uint32_t)cycleMs + random(0, 400)) {
                NodeReading r; readSensors(r);
                radio.sendData(r, nodeId, pendingSleepAck); lastAutoTx = millis();
                if (pendingSleepAck) {
                    rtcSleepMode = true;
                    rtcSilentWakes = 0;
                    rtcGpsFix = gpsFixCached; rtcLat = cachedLat; rtcLon = cachedLon;
                    enterDeepSleep(nextDuty(r));  // no return
                }
            }
        }
        if (millis() - lastBeaconAnyMs > 3UL * cycleMs) synced = false;   // lost base
    } else {
        // ---- autonomous fallback (no beacon heard) ----
        if (millis() - lastAutoTx > AUTO_TX_MS + (uint32_t)random(0, AUTO_JITTER_MS)) {
            NodeReading r; readSensors(r);
            radio.sendData(r, nodeId); lastAutoTx = millis();
            printReading(r);
        }
    }

    // ---- 3) GPS: acquire once, cache, power down ----
    if (!gpsFixCached) {
        double la = 0, lo = 0;
        gps.getCoordinates(la, lo);
        if (la != 0 && lo != 0) {
            cachedLat = la; cachedLon = lo; gpsFixCached = true;
            rtcGpsFix = true; rtcLat = la; rtcLon = lo;   // survives deep sleep
            Serial.printf("[GPS] fix cached: %.6f, %.6f\n", cachedLat, cachedLon);
#if GPS_SLEEP_AFTER_FIX
            power.gpsPower(false);
            Serial.println(F("[GPS] powered down (stationary meter)"));
#endif
        }
    }

    // ---- 4) button + display ----
    pollButton();
    if (editMode && millis() - editLastMs > EDIT_TIMEOUT_MS) { saveNodeId(); editMode = false; drawMain(); }
    if (displayOn && !editMode && millis() - lastActivity > DISPLAY_TIMEOUT_MS) sleepDisplay();
    if (displayOn && !editMode && millis() - lastDraw > 500) { lastDraw = millis(); drawMain(); }
}

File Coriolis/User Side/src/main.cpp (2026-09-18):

/**
 * Wind Receiver  -  LiLyGO T-Beam (ESP32)
 * =======================================
 * Central station. Listens for NodePackets from every wind node, keeps a table
 * of the most recent reading per node, and shows it on the OLED.
 *
 * Views (cycle with the middle/user button, GPIO 38):
 *   GENERAL  -> average wind speed + direction across all active nodes (startup).
 *   NODE n   -> that node's 2 s wind speed, direction, battery, distance, RSSI.
 *
 * Distance is computed from THIS receiver's GPS vs the node's GPS using the
 * Haversine helper in Location.h (returns yards).
 *
 * Compatibility: decodes the exact NodePacket the node transmitter sends.
 * Reuses your real Power.h (AXPManagement) and Location.h (GPSModule).
 *
 * Debug: every received packet and a periodic node table are printed to Serial.
 */

#include <Arduino.h>
#include <Wire.h>
#include <math.h>
#include <Preferences.h>

#include "Screen.h"
#include "Power.h"
#include "Environment.h"          // BMP085Sensor (baro) + GPSModule (GPS)
#include "Telemetry.h"
#include "Ballistics.h"            // standalone ballistic solver
#include "WindStats.h"             // rolling wind history + stability
// Cap the wind-sensitivity CURVE resolution. windSensitivity() runs one full
// trajectory integration per segment, so its cost is ~quadratic in range
// (segment count AND each shot's length both grow). The default cap (64) makes a
// 1500 yd curve ~57 s on this chip. Capping at 32 segments roughly halves that
// (~32 s) for ~2.6% curve error -- imperceptible on the bar chart, and it only
// affects the sensitivity CURVE, never the firing solution (solve()). Tune to
// taste: 24 -> ~24 s (~5% err), 16 -> ~16 s (~8% err), 64 -> full resolution.
// This overrides the #ifndef default inside Sensitivity.h; no header edit needed.
#define SENS_MAX_SEG 32
#include "Sensitivity.h"           // Phase 2: wind-sensitivity zones -> weights
#include "WebUI.h"                 // phone dashboard (WiFi AP)

// ============================================================================
// CONFIGURATION
// ============================================================================
#define I2C_SDA        21
#define I2C_SCL        22
#define GPS_RX_PIN     34
#define GPS_TX_PIN     12
#define BUTTON_PIN     38          // T-Beam user/middle button (active low)

#define MAX_NODES          16      // node ids 1..15
#define NODE_TIMEOUT_MS    60000UL // drop a node from "active" after 60 s silence

// ============================================================================
// FLEET SLEEP (piece 3 of 3 -- see DEEPSLEEP_v6.md)
// ============================================================================
// While fleetSleep is true every beacon carries BFLAG_SLEEP_CMD. Nodes ack and
// go down; each one then wakes on ITS OWN duty (20 s .. 5 min, chosen locally
// from its battery + temperature), listens for one beacon, transmits one
// reading, sleeps again. So during fleet sleep the beacon keeps running
// exactly as before -- it IS the check-in channel.
//
// Waking: pressing WAKE clears the flag and raises BFLAG_WAKE_CMD on every
// beacon for WAKE_BEACON_MS. 30 s covers a full default duty cycle with margin,
// so a 20 s node is caught on its very next check-in. Nodes that stretched to
// 5 min (cold/low battery) catch it later -- but the wake STATE is what nodes
// obey, not the 30 s burst: any check-in after WAKE is pressed finds the sleep
// flag gone and stays up. The burst just makes the common case feel instant
// and gives the UI a countdown to show.
//
// A sleeping node is silent for minutes at a time, so the normal 60 s activity
// timeout would evict the whole fleet from every list. Sleeping nodes get a
// timeout of 2x the max duty + margin instead.
#define WAKE_BEACON_MS        30000UL
#define SLEEP_NODE_TIMEOUT_MS 660000UL   // 2 x 300 s duty + 60 s margin

// ============================================================================
// AIMBOT: windage stepper controller (a SECOND ATtiny85, on THIS bus)
// ============================================================================
// Distinct from the node's wind-sensor ATtiny (0x42, different board). This one
// sits on the receiver's I2C bus and drives the scope's windage turret via a
// step/dir driver. The ESP32 sends it an absolute windage hold; the ATtiny does
// the click/step math and the motion. See attiny85_aimbot_stepper.ino.
#define AIMBOT_ADDR        0x33          // clear of PMU (0x34/0x35) and node (0x42)
#define AIM_CMD_SET_HOLD   0x01
#define AIM_CMD_GO         0x02
#define AIM_CMD_SET_AND_GO 0x03
#define AIM_CMD_ZERO       0x04
#define AIM_CMD_SET_ORIGIN 0x05
#define AIM_ST_MOVING      0x01
#define AIM_ST_AT_TARGET   0x02
#define AIM_ST_BADCSUM     0x04
#define AIM_ST_CLAMPED     0x08

bool aimbotPresent = false;              // probed at boot

// --- windage-stepper I2C helpers (were referenced but never defined) ---------
// Transport only; all motion/click math lives on the ATtiny (see the frame spec
// in attiny85_aimbot_stepper.ino): a fixed 4-byte little-endian frame
//   [0]=cmd  [1]=milliMOA low  [2]=milliMOA high  [3]=XOR of bytes 0..2
// and a single status byte read back. aimSend returns false on I2C NACK so the
// caller can report an error instead of assuming the turret moved.
void aimProbe() {
    Wire.beginTransmission(AIMBOT_ADDR);
    aimbotPresent = (Wire.endTransmission() == 0);
    Serial.println(aimbotPresent ? F("[aimbot] windage stepper FOUND at 0x33")
                                 : F("[aimbot] windage stepper absent"));
}

bool aimSend(uint8_t cmd, int16_t milliMoa) {
    uint8_t lo = (uint8_t)(milliMoa & 0xFF);
    uint8_t hi = (uint8_t)((milliMoa >> 8) & 0xFF);
    uint8_t frame[4] = { cmd, lo, hi, (uint8_t)(cmd ^ lo ^ hi) };  // XOR checksum
    Wire.beginTransmission(AIMBOT_ADDR);
    Wire.write(frame, sizeof(frame));
    return Wire.endTransmission() == 0;          // 0 = ACK
}

uint8_t aimStatus() {
    if (!aimbotPresent) return 0;                // don't poll an absent device
    if (Wire.requestFrom((uint8_t)AIMBOT_ADDR, (uint8_t)1) != 1) return 0;
    return (uint8_t)Wire.read();
}

#define SCREEN_REFRESH_MS  500UL
#define STATUS_PRINT_MS    5000UL
#define BATTERY_MS         2000UL
#define GPS_MS             1000UL
#define BUTTON_DEBOUNCE_MS 200UL
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

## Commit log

2025-08-16 Update Parts Lists
    Added a parts list. FAWD and User Interface are still in early development stages.
2025-08-16 Add files via upload
    Forgot to add the encoder housing plate.
    [PCF18_01-01-01-01 - Wind Meter Encoder Mtg PL.STL]
2025-08-17 Update main.cpp
    Updated the buzzer pin to pin 4.
    [main.cpp]
2025-08-23 Create Wiring Guide
2025-08-29 Update Wiring Guide
2025-12-13 Create Coriolis STL Files
2025-12-13 Add files via upload
    new firmware for the lilygo t beam.
    Currently only supports the MPU 6050. Working on extending compatibility to other more reliable IMUs.
2026-01-13 Refactor main.cpp for target device configuration
2026-07-14 Create CAD
2026-07-21 Update Readme with PCB ordering advice
    Added recommendation for PCB ordering process.
2026-07-21 Revise Coriolis BOM with updated parts and notes
    Updated the Coriolis Bill of Materials to reflect changes in parts and recommendations for assembly.
2026-07-21 Update Coriolis BOM
2026-07-25 Add BOM for Wind Meter components
    Added purchase links for Inspeed Wind Meter and Sparkfun Weather Meter components.
2026-09-18 Enhance GPS module for better data handling
    Updated GPS module to handle UART buffer overflow and improve coordinate retrieval.
2026-09-18 Fix time comparison and sample counting in WindStats
    Updated time comparison logic to be rollover-safe and fixed issues with sample counting during millis() rollover.
2026-09-18 Implement deep sleep and I2C recovery mechanisms
    Added deep sleep functionality and I2C bus recovery logic.
2026-09-18 Refactor Motion class and add IMU auto-detection
    Refactored Motion class and implementations, added auto-detection for IMUs.
2026-09-18 Implement battery charging control in Power.h
    Added method to enable or disable battery charging based on temperature conditions.
2026-10-26 ATtiny: require an explicit wind meter selection at compile time
    FORCE_SENSOR was set to 1 (SparkFun) while its comment said Inspeed, so an
    Inspeed node flashed as-is read 40% low with the wrong vane decoder.
    Replace it with two WIND_METER_ lines; the build now fails unless exactly
    one is uncommented. Remove the unreachable auto-detect probe and fix the
    debounce cap comment. Boot LED still blinks 2 (SparkFun) / 3 (Inspeed).
    Claude-Session: https://claude.ai/code/session_015KDJgc1ijcidRypS5cWPjX
2026-10-27 Node: watchdog, crash-proof sleep state, and reset-reason logging
    A deployed node could freeze while asleep and stay dark until someone
    pressed reset. Nothing watched for a hang, and any non-deep-sleep reset
    (watchdog, panic, brownout, the I2C esp_restart) wiped RTC_DATA_ATTR
    state, so the node came back fully awake and the I2C self-reset cap
    never held.
    - Arm the task watchdog (30 s) on the loop task; feed it in loop() and
    in the sleep check-in listen loop.
    - Move the sleep/RTC state to RTC_NOINIT_ATTR guarded by a magic word;
    defaults are applied only on power-on/reset button or bad magic.
    - A node that was asleep and resets unexpectedly goes straight back to
    its check-in cycle.
    - L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
2026-11-04 ATtiny: correct wind statistics, 16-position vane, bounce rejection, watchdog
    Replaces PR #14's estimator, keeping its per-pulse timing, atomic I2C
    publish and PROGMEM table.
    - Speed averages over the whole 10 s window, so calm time counts as calm.
    #14 divided by summed revolution time (a 1 s burst then calm read ~4x
    too high) and counted the revolution in progress as complete (one lone
    pulse could publish up to 250 mph).
    - Gust is pulses in the best 3 s span / 3 s, a true 3 s mean.
    - SparkFun vane table now has all 16 positions. The 8-entry table decoded
    in-between positions up to 112.5 deg wrong. Field angle convention kept.
    - A closure only counts after the line was open >= 1.5 m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
2026-11-04 Node: radio-start retry, charge-state sync, brownout rest, sleep fixes
    Builds on #16 (watchdog + RTC_NOINIT state).
    - Retry radio.begin(). A failed start used to leave the node silent
    forever while the watchdog stayed fed -- a direct match for "frozen in
    the cold until reset". Sleeping nodes retry once, then sleep and try
    again next wake; awake nodes retry every 10 s.
    - After a brownout, rest for the max duty before using the radio,
    instead of rebooting straight into another transmit and looping.
    - Charge control: setChargeEnable() now reads the PMU bit back and only
    reports success if it took. On boot, the PMU is synced to the stored
    state, so a reset can no longer leave chargi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
2026-11-11 Solver: fix inverted aero-jump sign and reject an unzeroed solution
    Aero jump was applied with the wrong sign. The solver defines
    crossMph > 0 as wind from the right, and a right-twist bullet in a wind
    from the right is deflected UP (the same wind that drifts it left), but
    the code computed twistDir * Y * (-crossMph), which sends it down. The
    old comment stated the correct physics and then mapped it to the wrong
    sign of crossMph. For a 175 gr .308 at 10 mph full value this moved the
    elevation answer about 0.47 MOA the wrong way, so the come-up was off by
    about 0.94 MOA in total.
    The zero search was also unchecked. With zero_yd <= 0 both probe shots
    return immediately with the same height, t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
2026-11-11 Node: sleep check-in borrows a spare slot, not an awake node's slot
    A sleeping node that the beacon has not scheduled (always the case for a
    per-node-slept node, because the base drops it from node_mask) picked its
    check-in slot as (id-1) % max_slot + 1. max_slot is the number of
    scheduled nodes, and those nodes are awake and transmit in slots
    1..max_slot every cycle, so the check-in always landed on top of an awake
    node's packet. The two transmissions overlap almost completely, so the
    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
2026-11-12 Receiver: old wind must not vote on the phone either; disarm aimbot on solver error
    The base stopped counting wind older than 60 s in its own average, but
    /data.json still sent windOk from the meter-valid flag alone. The phone
    builds the WIND HOLD, the solver wind, the aimbot hold and the log from
    windOk, so a sleeping node's reading kept voting there for up to 11
    minutes, and the phone's meter count could disagree with avg.count.
    windOk now means exactly "this node is in the base's wind vote" (taken
    from the same list the base average used, so the two always match). A
    new windStale flag says the meter is fine but the reading is too old, and
    the node tab shows OLD READING for that case inst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
2026-11-12 Node: stalled-ATtiny check no longer fooled by the 63 s sequence wrap
    The ATtiny publish sequence is 6 bits and wraps every 63 publishes (about
    63 s). The stall check compared the first read after a deep sleep with
    the value saved before the sleep, so on the 60 s sleep duty, where a node
    wakes every 61 to 66 s, a healthy ATtiny regularly showed the same value
    and its wind was marked invalid. A model of the timing puts that at about
    a third of check-ins with the ATtiny ticking at exactly 1 s.
    The node now samples the sequence once at the start of a timer wake. A
    match with the pre-sleep value only counts as a stall if the sequence has
    also not moved since that sample, at least 1.5 s earlier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
2026-11-12 Update the ATtiny85 wind sensor over I2C (twiboot bootloader)
    - attiny85_bootloader/: twiboot (GPLv2, upstream 559a403) built for the
    ATtiny85 at I2C 0x43, with fixes for four upstream bugs that stop it
    working on this board: reset vector jumped to 0x1800, application start
    called a byte address as a word address, USI NAKed the last byte of page
    writes, SCL was driven push-pull around start/exit. LED moved off the
    anemometer pin, watchdog cleared at start. 988 bytes; sketches up to
    7168 bytes.
    - Sketch: writing {0x01, 0x00} to 0x42 resets into the bootloader.
    - Node: lib/AttinyFlasher writes and verifies the image (reset vector last,
    so an interrupted update stays in the bootlo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
2026-11-12 Add combine_hex.py: bootloader and sketch in one ISP step
    Writes the vectors the way twiboot does after an I2C upload; the simulator
    test takes the combined image as an optional fourth argument and checks the
    sketch starts on its own and the bootloader reads it back as the sketch.
    Claude-Session: https://claude.ai/code/session_01UBBdsReuB6YTG3k1843M5R
2026-11-12 ATtiny: count bouncing closures again; ignore chatter when the contact opens
    The bounce filter from 06b3f43 read the pin level a few us after each edge.
    On a reed that bounces as it closes, that read was often HIGH, which reset the
    "open for 1.5 ms" timer, so the rest of the closure was rejected and the pulse
    was lost. On the bench an Inspeed cup spun by hand read 0.3-0.5 mph instead of
    real speeds. Chatter as the contact opened was counted as a second pulse.
    A pulse is now the first edge after the line has rested open for 1.5 ms,
    whatever level is read afterwards. The read only records whether the line is
    resting open or closed.
    Simulated on simavr with the Inspeed WS2 build (4 Hz, 20 ms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
2026-11-12 CI: lower-case header aliases for the Linux build (sources use Windows file-name case)
    Claude-Session: https://claude.ai/code/session_01UBBdsS79VASoU7uL97Jzb7
2026-11-12 CI: merge with pip esptool 4.x; find boot_app0.bin in any framework package
    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
2026-11-12 CI: pin espressif32 7.0.1 and the library versions used on the maintainer's PC
    The repo's unpinned platform now resolves to espressif32 8.0.0 (Arduino
    core 3.3) in a fresh environment, while the PC builds that were
    hardware-tested use 7.0.1 (core 2.0.17). Pin that, the libraries it
    resolved, and the XPowersLib commit. Strip CRLF before editing
    platformio.ini, and keep each project's own partition table.
    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
2026-11-12 CI: optional hand-run step that attaches the images to a draft release
    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
2026-11-12 Add step-by-step ATtiny85 first-time setup guide (Arduino UNO as ISP)
    Beginner walkthrough for the one-time chip setup that the I2C bootloader
    needs: ArduinoISP on the UNO, wiring with the 10 uF reset capacitor,
    finding avrdude, the V1.2.0 isp_with_bootloader file per wind meter,
    the one-line fuse + flash command, LED check, moving the chip, later
    I2C updates, what never to do afterwards, and troubleshooting.
    Linked from the root README and the bootloader README.
    Claude-Session: https://claude.ai/code/session_01UBBdsMiZpq8pTRXPfZ9oUk
